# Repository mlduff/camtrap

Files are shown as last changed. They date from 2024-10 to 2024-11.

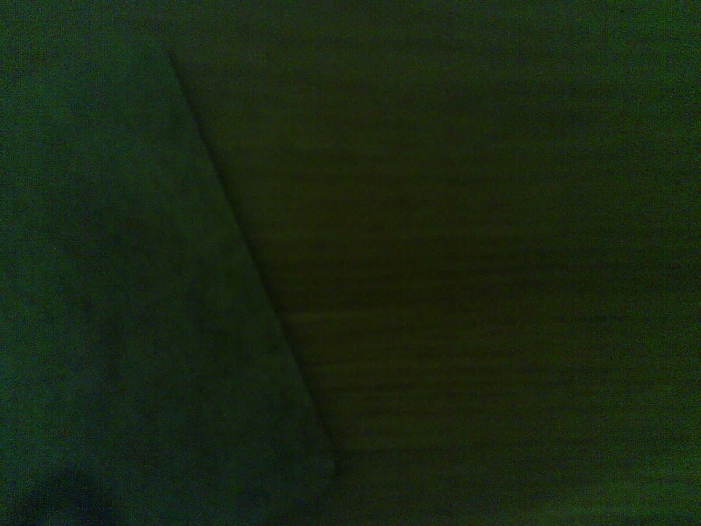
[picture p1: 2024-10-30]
server/images/8019c0cc-56fd-4880-98f8-5ad1f4f78f04.jpeg

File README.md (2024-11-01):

# Camtrap
This project provides the ability to create a DIY home monitoring system. Each device will automatically detect movement within a certain distance, taking a photo and saving it to a central server when triggered. Devices can be enabled or disabled remotely via the server, or physically with an RFID-tag.
# Parts List
This project requires the following parts:
- ESP32 Freenove WROVER CAM Module
- STM32 Nucleo-64
- Wires

# Setup
To setup this project, follow the following guides in order:
1. [Server](server/README.md)
2. [Device](device/README.md)
3. [ESP32](device/client/README.md)

# User Manual
## Recording RFID tag
1. Navigate to the page of the device you want to use to add an RFID tag
2. Enable configure mode
3. Swipe the RFID tag against the reading panel
4. Navigate to the RFID tags page and verify that the tag has been navigated
5. Navigate back to the device page and disable configure mode

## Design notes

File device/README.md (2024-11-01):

# Setup
This section contains the physical setup required to connect the two parts of the device together.
## UART Connection
A wire must be connected between pin 33 on the ESP32 and pin PA10 on the STM32. A wire must also be connected between pin 32 on the ESP32 and pin PA9 on the STM32.
## RFID Sensor
Connect:
- PA6 to MISO
- PA7 to MOSI
- PB3 to SCLK
- PA4 to SS
- PB4 to RST
- GND to GND
## Motion Sensor
Connect:
- PC4 to input
- 5V to VCC
- GND to GND
## Distance Sensor
Connect:
- SCL to SCL
- SDA to SDM
- 3v3 to VCC
- GND to GND
## Green LED
Connect pin 2 on the ESP32 to the positive side of the LED, and then then ground the other side to one of the ground pins on the ESP32
## Red LED
Connect pin 14 on the STM32 to the positive side of the LED, and then then ground the other side to one of the ground pins on the STM32

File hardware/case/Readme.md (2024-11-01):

# Models:
This folder includes a set of 3D models that were used for a case in the original design. The case included a main body with an integrated ESP dock and sensor holes, a sliding lid, an additional shroud for the STM to allow easy removal, inserts to allow easier positioning of the sensors, and a stand to elevate the case and allow cables underneath.

## Main Box:
The main box includes a housing for an ESP32-WROVER unit, space for an STM32 in the provided shroud, a passive infrared sensor, and a laser distance sensor. Holes are also provided for the charging cables for both units, at the bottom. This can either be a free-standing unit using the included stand, or you can drill some holes in the backplate and hang it on the wall. 

## Inserts:
The inserts were added to make it easier to position the sensors. Think of them as guides that you can stick to the box, covering the bigger holes. You can also either incorporate these into the case in external software or just make your own holes, if you want.

## Printing Instructions:
All parts were printed at 100% size with PLA filament. You may want to dial in your printer before printing, as the cover can be a bit finnicky to get sliding.

## Additional Securing:
We used bluetack to stick everything together, including keeping the sensors in place and mounting the inserts. I would suggest something more robust like glue for use in a proper environment, or possibly something like electrical tape - however, bluetack served as a low-cost, safe, and non-damaging way to temporarily mount our components. You can also add some velcro strips to the STM shroud to make it secure, but removable.

## Modifications:
After printing, I personally had to expand the STM power port hole as the cable we were using was much bigger than usual. If you have a normal small cable, you may be fine, but otherwise, either take like a dremel to it or modify the STL in software - TinkerCad is a good option.

## Credits:
https://www.thingiverse.com/thing:2695555/files by stefanino, slightly modified.

https://www.printables.com/model/313510-general-purpose-esp32-wrover-web-cam-module-mount/files by robertgriffiths, also modified.

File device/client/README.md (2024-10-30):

# Client
The client package contains the client firmware, designed to run on the ESP32.

# Configuration
These instructions will assist you with the setup for this project, but assume you know how to use the ESP-IDF framework.

## Software Configuration
To get the software running on an ESP32, follow these instructions:
1. Open the menuconfig editor of your choice
2. Select the device target to be ESP-WROVER-KIT 3.3V
3. Select UART as the flash method
4. Attach the ESP32 to the computer and select the correct COM PORT
6. Run build, flash and start a monitor command

## User Configuration
Once you have the ESP32 running the project software, follow these instructions to connect it to your home system.
1. Ensure that the server is running
2. Attach the ESP32 to power
3. Using a device not running the server:
    1. Connect to the local WiFi network with the configured name (default is `camtrap-device`)
    2. Navigate to http://192.168.4.1/ in a browser
    3. Enter your WiFi network details as well as the address of the device running your server
    4. Submit
4. Check that the ESP32 network is no longer available and that the device has been registed by navigating to the `/devices/` page on your server. Repeat from step 3 if there are any issues (most likely incorrect details)

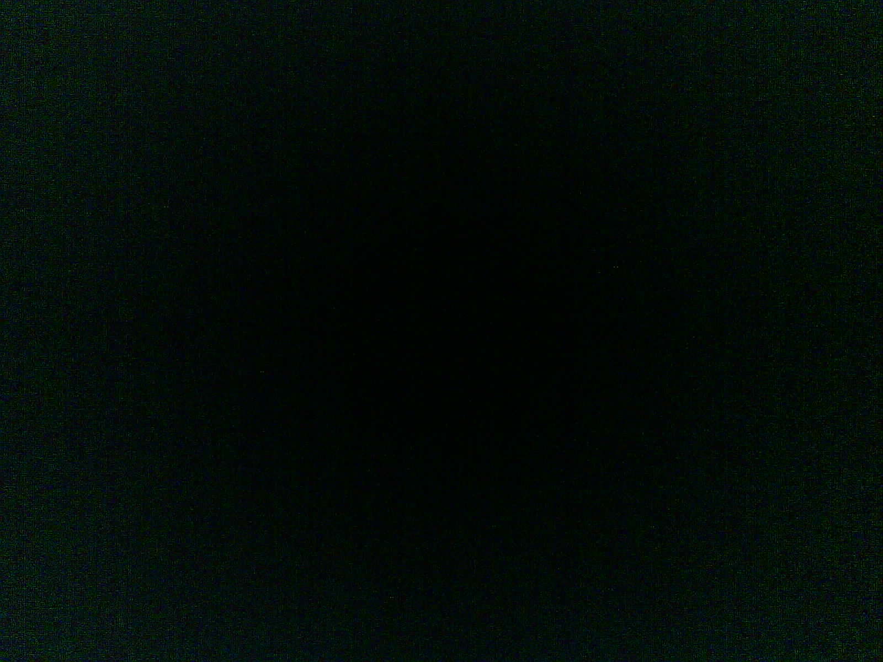
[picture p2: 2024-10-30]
server/images/8084e82d-38a2-4b22-b4e9-9dc468efb220.jpeg

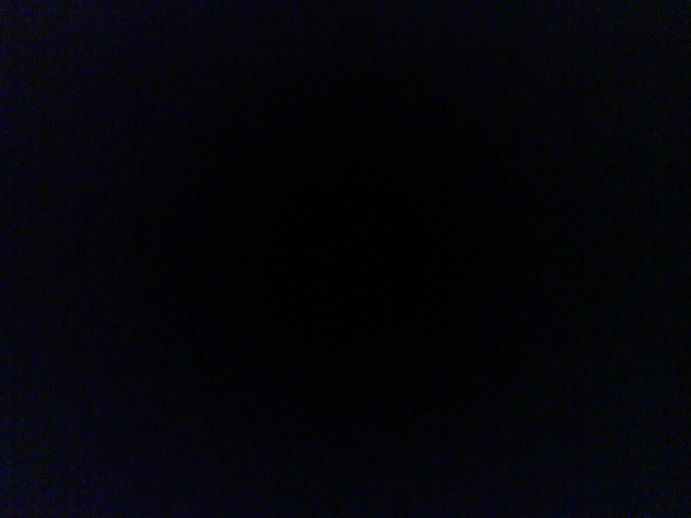
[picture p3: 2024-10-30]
server/images/77ac3b3d-4b93-4aa5-b343-f92d32466588.jpeg

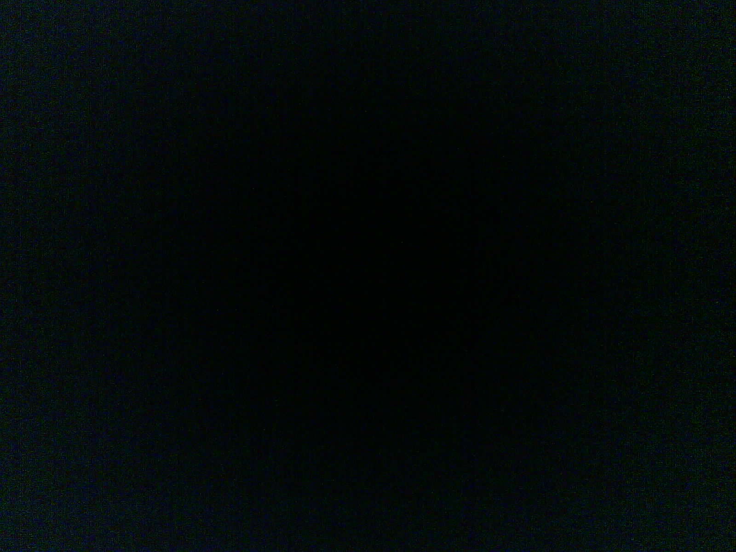
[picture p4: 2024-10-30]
server/images/544a1262-dc36-4d9c-8306-14e966307e1b.jpeg

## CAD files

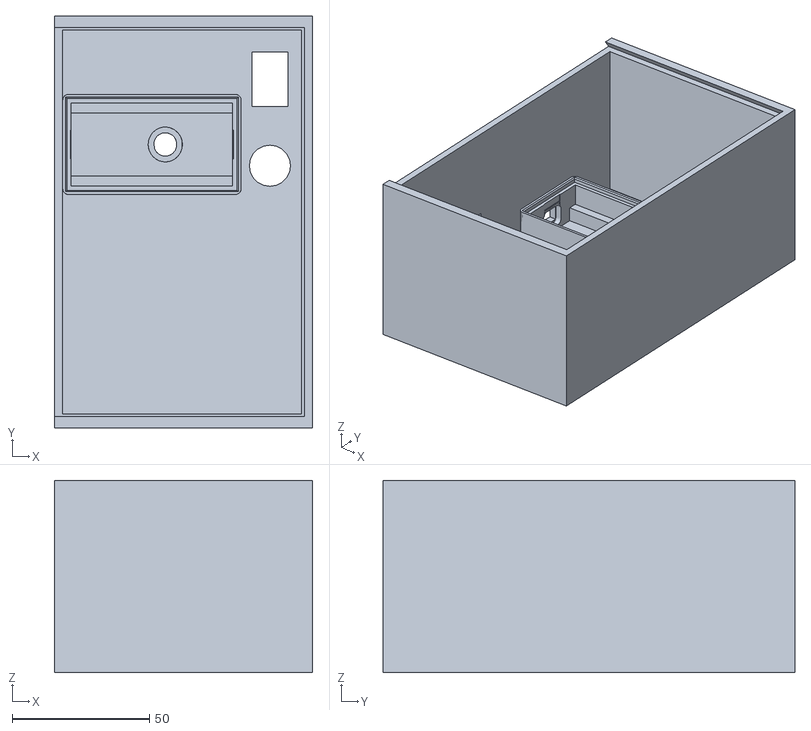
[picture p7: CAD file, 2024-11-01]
hardware/case/Main_Box_With_ESP_Dock.stl
94.0 x 150.0 x 70.0

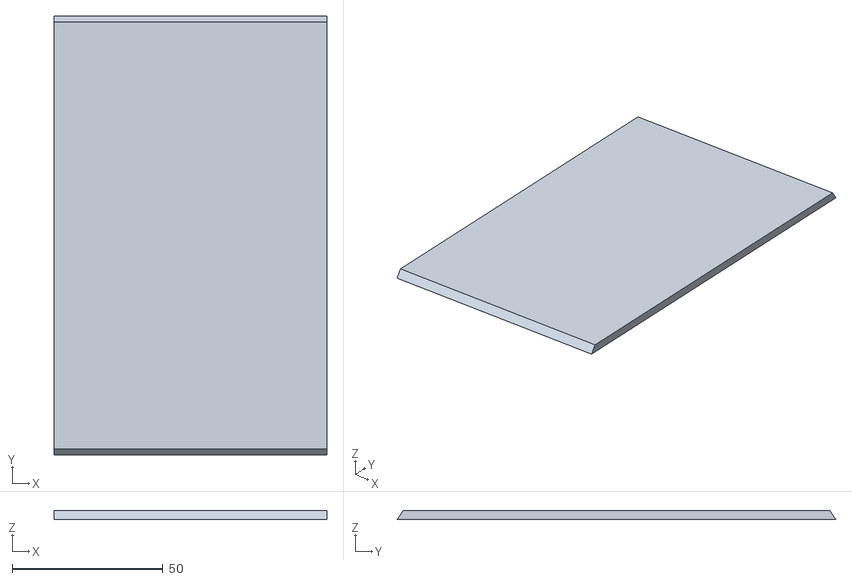
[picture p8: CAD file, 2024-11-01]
hardware/case/Main_Box_Lid.stl
90.5 x 145.5 x 3.00

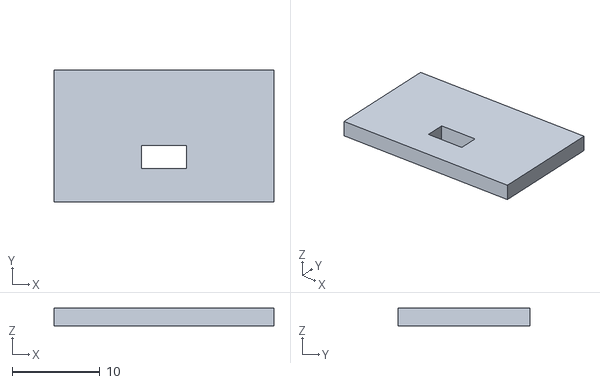
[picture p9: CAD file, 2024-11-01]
hardware/case/Laser_Distance_Sensor_Insert.stl
25.0 x 15.0 x 2.00

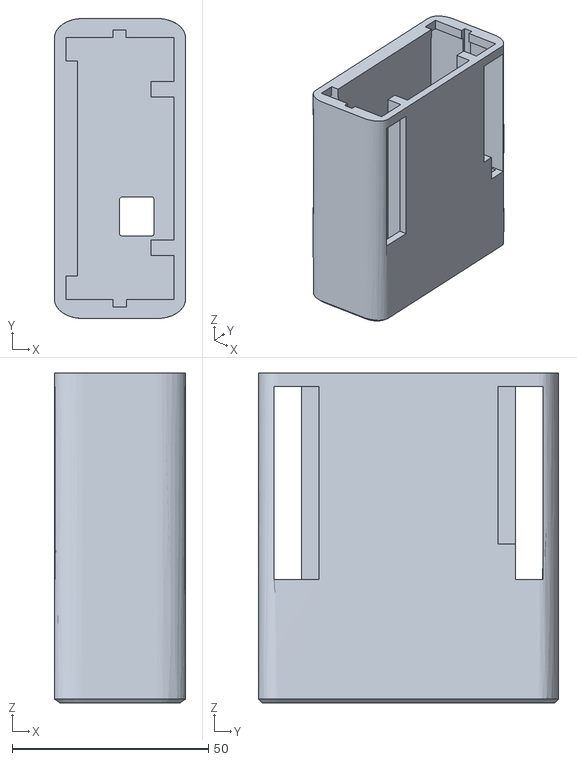
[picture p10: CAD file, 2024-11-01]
hardware/case/STM_Shroud.stl
33.4 x 76.4 x 84.0

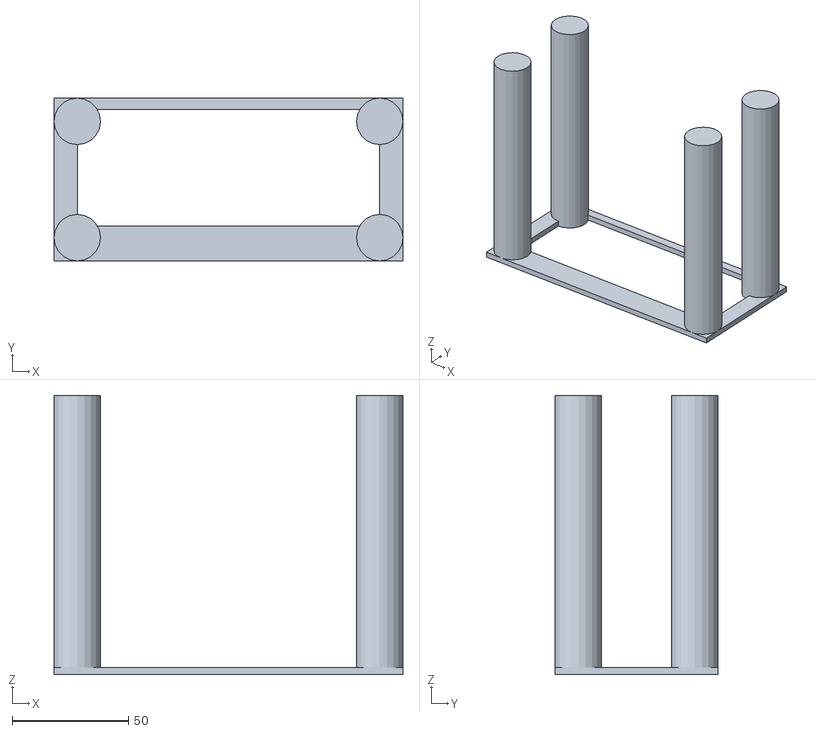
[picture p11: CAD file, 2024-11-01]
hardware/case/Stand.stl
150.0 x 70.0 x 120.0

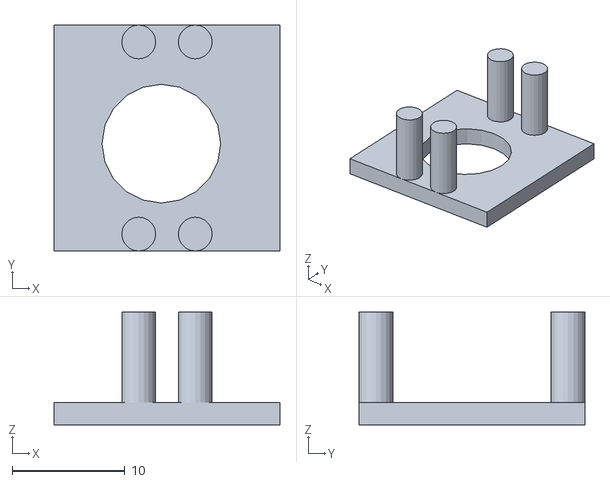
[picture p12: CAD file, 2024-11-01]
hardware/case/PIR_Insert.stl
20.0 x 20.0 x 10.0

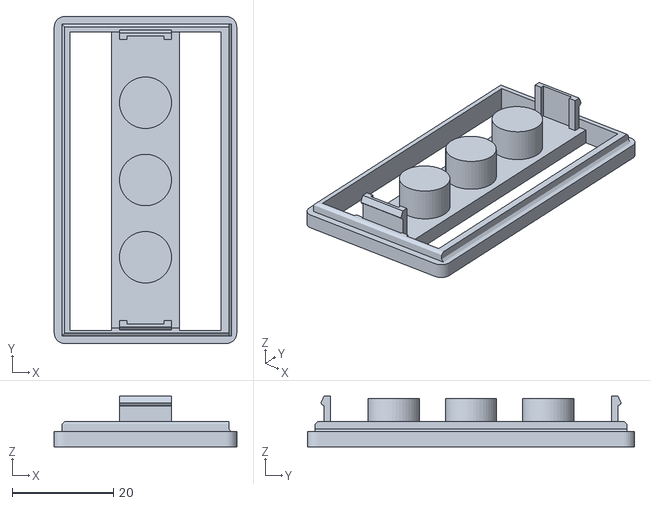
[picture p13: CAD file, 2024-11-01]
hardware/case/ESP_32_Dock_Lid.stl
36.0 x 64.5 x 10.0

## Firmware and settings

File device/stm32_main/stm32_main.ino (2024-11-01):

#include <Wire.h>
#include <VL53L1X.h>
#include <STM32FreeRTOS.h>
#include <SPI.h>
#include <MFRC522.h>

#define UART_Tx         PA9
#define UART_Rx         PA10
#define PIR_IN          PC4
#define SS_PIN          PA4
#define RST_PIN         PB4

#define TARGET_DISTANCE 5000

SemaphoreHandle_t pirSemaphore;
SemaphoreHandle_t laserSemaphore;
SemaphoreHandle_t uartSemaphore;

bool pirValue = false;
bool laserValue = false;

HardwareSerial mySerial(USART3);

static void pirReadThread(void* arg) {
  UNUSED(arg);
  pinMode(PIR_IN, INPUT);

  while (1) {
    if (digitalRead(PIR_IN) == HIGH) {
      if (xSemaphoreTake(pirSemaphore, (TickType_t) 5) == pdTRUE) {
        pirValue = true;
        xSemaphoreGive(pirSemaphore);
      }
    } else {
      if (xSemaphoreTake(pirSemaphore, (TickType_t) 5) == pdTRUE) {
        pirValue = false;
        xSemaphoreGive(pirSemaphore);
      }
    }
  }
}

static void laserRangeReadThread(void* arg) {
  UNUSED(arg);
  VL53L1X sensor;
  Wire.begin();
  Wire.setClock(400000); 

  sensor.setTimeout(500);
  if (!sensor.init())
  {
    Serial.println("Failed to detect and initialize sensor!");
    while (1);
  }

  sensor.setDistanceMode(VL53L1X::Long);
  sensor.setMeasurementTimingBudget(50000);

  sensor.startContinuous(50);

  while (1) {
    if (sensor.read() < TARGET_DISTANCE) {
      if (xSemaphoreTake(laserSemaphore, (TickType_t) 5) == pdTRUE) {
        laserValue = true;
        xSemaphoreGive(laserSemaphore);
      }
    } else {
      if (xSemaphoreTake(laserSemaphore, (TickType_t) 5) == pdTRUE) {
        laserValue = false;
        xSemaphoreGive(laserSemaphore);
      }
    }
    if (sensor.timeoutOccurred()) { Serial.print(" TIMEOUT"); }
  }
}

static void processingThread(void* arg) {
  UNUSED(arg);

  pinMode(LED_BUILTIN, OUTPUT);

  bool alarmTriggered = false;

  while (1) {
    if (alarmTriggered == true) {
      alarmTriggered = false;
      vTaskDelay((500L * configTICK_RATE_HZ) / 1000L);
    }
    if (xSemaphoreTake(pirSemaphore, (TickType_t) 10) == pdTRUE) {
      if (xSemaphoreTake(laserSemaphore, (TickType_t) 10) == pdTRUE) {
        if (pirValue == true && laserValue == true) {
          Serial.println("INTRUDER DETECTED!!!");
          alarmTriggered = true;
          digitalWrite(LED_BUILTIN, HIGH);
          vTaskDelay((1000L * configTICK_RATE_HZ) / 1000L);
          if (xSemaphoreTake(uartSemaphore, (TickType_t) 10) == pdTRUE) {
            mySerial.print("alarm");
            xSemaphoreGive(uartSemaphore);
          }
          vTaskDelay((5000L * configTICK_RATE_HZ) / 1000L);
          digitalWrite(LED_BUILTIN, LOW);
        }
        xSemaphoreGive(laserSemaphore);
      }
      xSemaphoreGive(pirSemaphore);
    }
  }
}

static void rfidTask(void* arg) {
  UNUSED(arg);

  Serial.println("Beginning RFID task.");

  MFRC522 rfid(SS_PIN, RST_PIN); // Instance of the class
  MFRC522::MIFARE_Key key;

  SPI.setMISO(PA6);
  SPI.setMOSI(PA7);
  SPI.setSCLK(PB3);
  SPI.begin(); // Init SPI bus
  rfid.PCD_Init(); // Init MFRC522

  while (1) {
    // Check if a card is present
    if (!rfid.PICC_IsNewCardPresent()) {
      vTaskDelay(100 / portTICK_PERIOD_MS);
      continue; // If no card is present, return
    }

    // Check if we can read the card
    if (!rfid.PICC_ReadCardSerial()) {
      continue; // If the card can't be read, return
    }

    // Print card UID
    Serial.print("Tag UID: ");
    String rfidUid = "";
    for (byte i = 0; i < rfid.uid.size; i++) {
      rfidUid += rfid.uid.uidByte[i] < 0x10 ? " 0" : " ";
      rfidUid += String(rfid.uid.uidByte[i], HEX);
    }

    if (xSemaphoreTake(uartSemaphore, (TickType_t) 10) == pdTRUE) {
      mySerial.print("rfid" + rfidUid);
      xSemaphoreGive(uartSemaphore);
    }

    Serial.println(rfidUid);

    // Check card type
    MFRC522::PICC_Type piccType = rfid.PICC_GetType(rfid.uid.sak);
    Serial.print("PICC Type: ");
    Serial.println(rfid.PICC_GetTypeName(piccType));

    // Check if the card is of type MIFARE TNP3XXX
    if (piccType == MFRC522::PICC_TYPE_MIFARE_MINI) {
      Serial.println("MIFARE TNP3XXX tag detected!");
    } else {
      Serial.println("Different tag type detected.");
    }

    // Halt PICC
    rfid.PICC_HaltA();
    
    // Stop encryption on PCD
    rfid.PCD_StopCrypto1();

    // Wait for the tag to be removed
    while (rfid.PICC_IsNewCardPresent() || rfid.PICC_ReadCardSerial()) {
      vTaskDelay(100 / portTICK_PERIOD_MS); // Delay to allow time for the tag to be removed
    }
  }
}

void readUartTask(void* arg) {
  UNUSED(arg);

  while (mySerial.available()) {
    mySerial.read(); // Clear any existing data
  }

  if (xSemaphoreTake(uartSemaphore, (TickType_t) 10) == pdTRUE) {
    mySerial.print("start");
    xSemaphoreGive(uartSemaphore);
  }

  String incoming;
  while (1) {
    if (mySerial.available() > 0) {
      incoming = mySerial.readStringUntil('\n');
      incoming.trim();

      Serial.print("I received: " + incoming);
    }
    vTaskDelay(100 / portTICK_PERIOD_MS); // Add a delay to prevent tight looping
  }
}

void setup()
{
  portBASE_TYPE pirThread, laserThread, processThread, rfidThread, readUartThread;

  Serial.begin(9600);
  while (!Serial) {}

  Serial.println("Setting up...");

  // Initialize UART Serial
  mySerial.setRx(UART_Rx);
  mySerial.setTx(UART_Tx);
  mySerial.begin(9600);

  pirSemaphore = xSemaphoreCreateMutex();
  laserSemaphore = xSemaphoreCreateMutex();
  uartSemaphore = xSemaphoreCreateMutex();

  pirThread = xTaskCreate(pirReadThread, NULL, 512, NULL, 1, NULL);

  laserThread = xTaskCreate(laserRangeReadThread, NULL, 768, NULL, 1, NULL);

  processThread = xTaskCreate(processingThread, NULL, 512, NULL, 1, NULL);

  rfidThread = xTaskCreate(rfidTask, NULL, 1024, NULL, 1, NULL);

  readUartThread = xTaskCreate(readUartTask, NULL, 512, NULL, 1, NULL);

  if (
    pirSemaphore == NULL || 
    laserSemaphore == NULL ||
    uartSemaphore == NULL ||
    pirThread != pdPASS ||
    laserThread != pdPASS ||
    processThread != pdPASS ||
    rfidThread != pdPASS ||
    readUartThread != pdPASS
  ) {
    Serial.println(F("Creation problem"));
    while(1);
  }

  vTaskStartScheduler();
}

void loop()
{
  
}

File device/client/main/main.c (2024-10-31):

#include <esp_log.h>
#include <esp_err.h>
#include "nvs_flash.h"
#include "esp_camera.h"

#include "communications/wifi.h"
#include "communications/network.h"
#include "communications/uart.h"
#include "communications/requests/connect.h"
#include "communications/requests/alarm.h"
#include "camera/camera.h"
#include "storage/enabled.h"
#include "storage/wifi_ssid.h"
#include "storage/wifi_password.h"
#include "led/led.h"

#ifdef CONFIG_DEFAULT_ENABLED
#define DEFAULT_ENABLED true
#else
#define DEFAULT_ENABLED false
#endif

static const char *TAG = "client:main";

void init_spiffs();
void start_webserver(void);

void app_main(void)
{
    led_init();

    esp_err_t err;
    err = nvs_flash_init();
    if (err == ESP_ERR_NVS_NO_FREE_PAGES || err == ESP_ERR_NVS_NEW_VERSION_FOUND)
    {
        ESP_ERROR_CHECK(nvs_flash_erase());
        err = nvs_flash_init();
    }
    ESP_ERROR_CHECK(err);

    bool enabled;
    err = get_enabled(&enabled);
    if (err == ESP_OK) {
        ESP_LOGI(TAG, "Enabled status=%s.", enabled ? "true" : "false");
    }
    else if (err == ESP_ERR_NVS_NOT_FOUND)
    {
        ESP_LOGI(TAG, "Initializing enabled to %s.", DEFAULT_ENABLED ? "true" : "false");
        enabled = DEFAULT_ENABLED;
        set_enabled(enabled);
    }
    
    led_set(enabled);

    start_uart();
    ESP_LOGI(TAG, "Started UART task.");

    ESP_LOGI(TAG, "Performing common WiFi initialization.");
    wifi_init();

    network_start();

    start_webserver();

    init_spiffs();

    err = camera_init();
    if (err != ESP_OK)
    {
        ESP_LOGE(TAG, "Camera initialization failed.");
        return;
    }

    ESP_LOGE(TAG, "Camera initialization succeeded.");
}

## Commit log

2024-10-31 UI improvements and LED from ESP
2024-10-31 Updated STM code with LED and removed receiver
2024-11-01 Update code, add models
    [ESP_32_Dock_Lid.stl, Laser_Distance_Sensor_Insert.stl, Main_Box_Lid.stl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]
